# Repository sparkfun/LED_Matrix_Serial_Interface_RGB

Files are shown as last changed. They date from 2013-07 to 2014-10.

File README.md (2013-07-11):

LED Matrix Serial Interface-RGB
===============================

[LED Matrix-Serial Interface RGB  
*LED Matrix - Serial Interface RGB (COM-00760)*](https://www.sparkfun.com/products/760)

This is a large sized RGB LED matrix with a backpack that has been designed to take SPI serial input and display any graphics you pass it.

Repository Contents
-------------------
* **/Firmware** - Any firmware that the part ships with, 
* **/Hardware** - All Eagle design files (.brd, .sch, .STL)

License Information
-------------------
The hardware is released under [Creative Commons Share-alike 3.0](http://creativecommons.org/licenses/by-sa/3.0/).  
All other code is open source so please feel free to do anything you want with it; you buy me a beer if you use this and we meet someday ([Beerware license](http://en.wikipedia.org/wiki/Beerware)).

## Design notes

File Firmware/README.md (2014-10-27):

LED Matrix Serial Interface RGB Firmware
=======================================

* Arduino_Examples - Example Arduino sketch for interfacing with the LED Matrix
* RGB_Backpack_v5 - Firmware that ships installed on the LED Matrix Backpack

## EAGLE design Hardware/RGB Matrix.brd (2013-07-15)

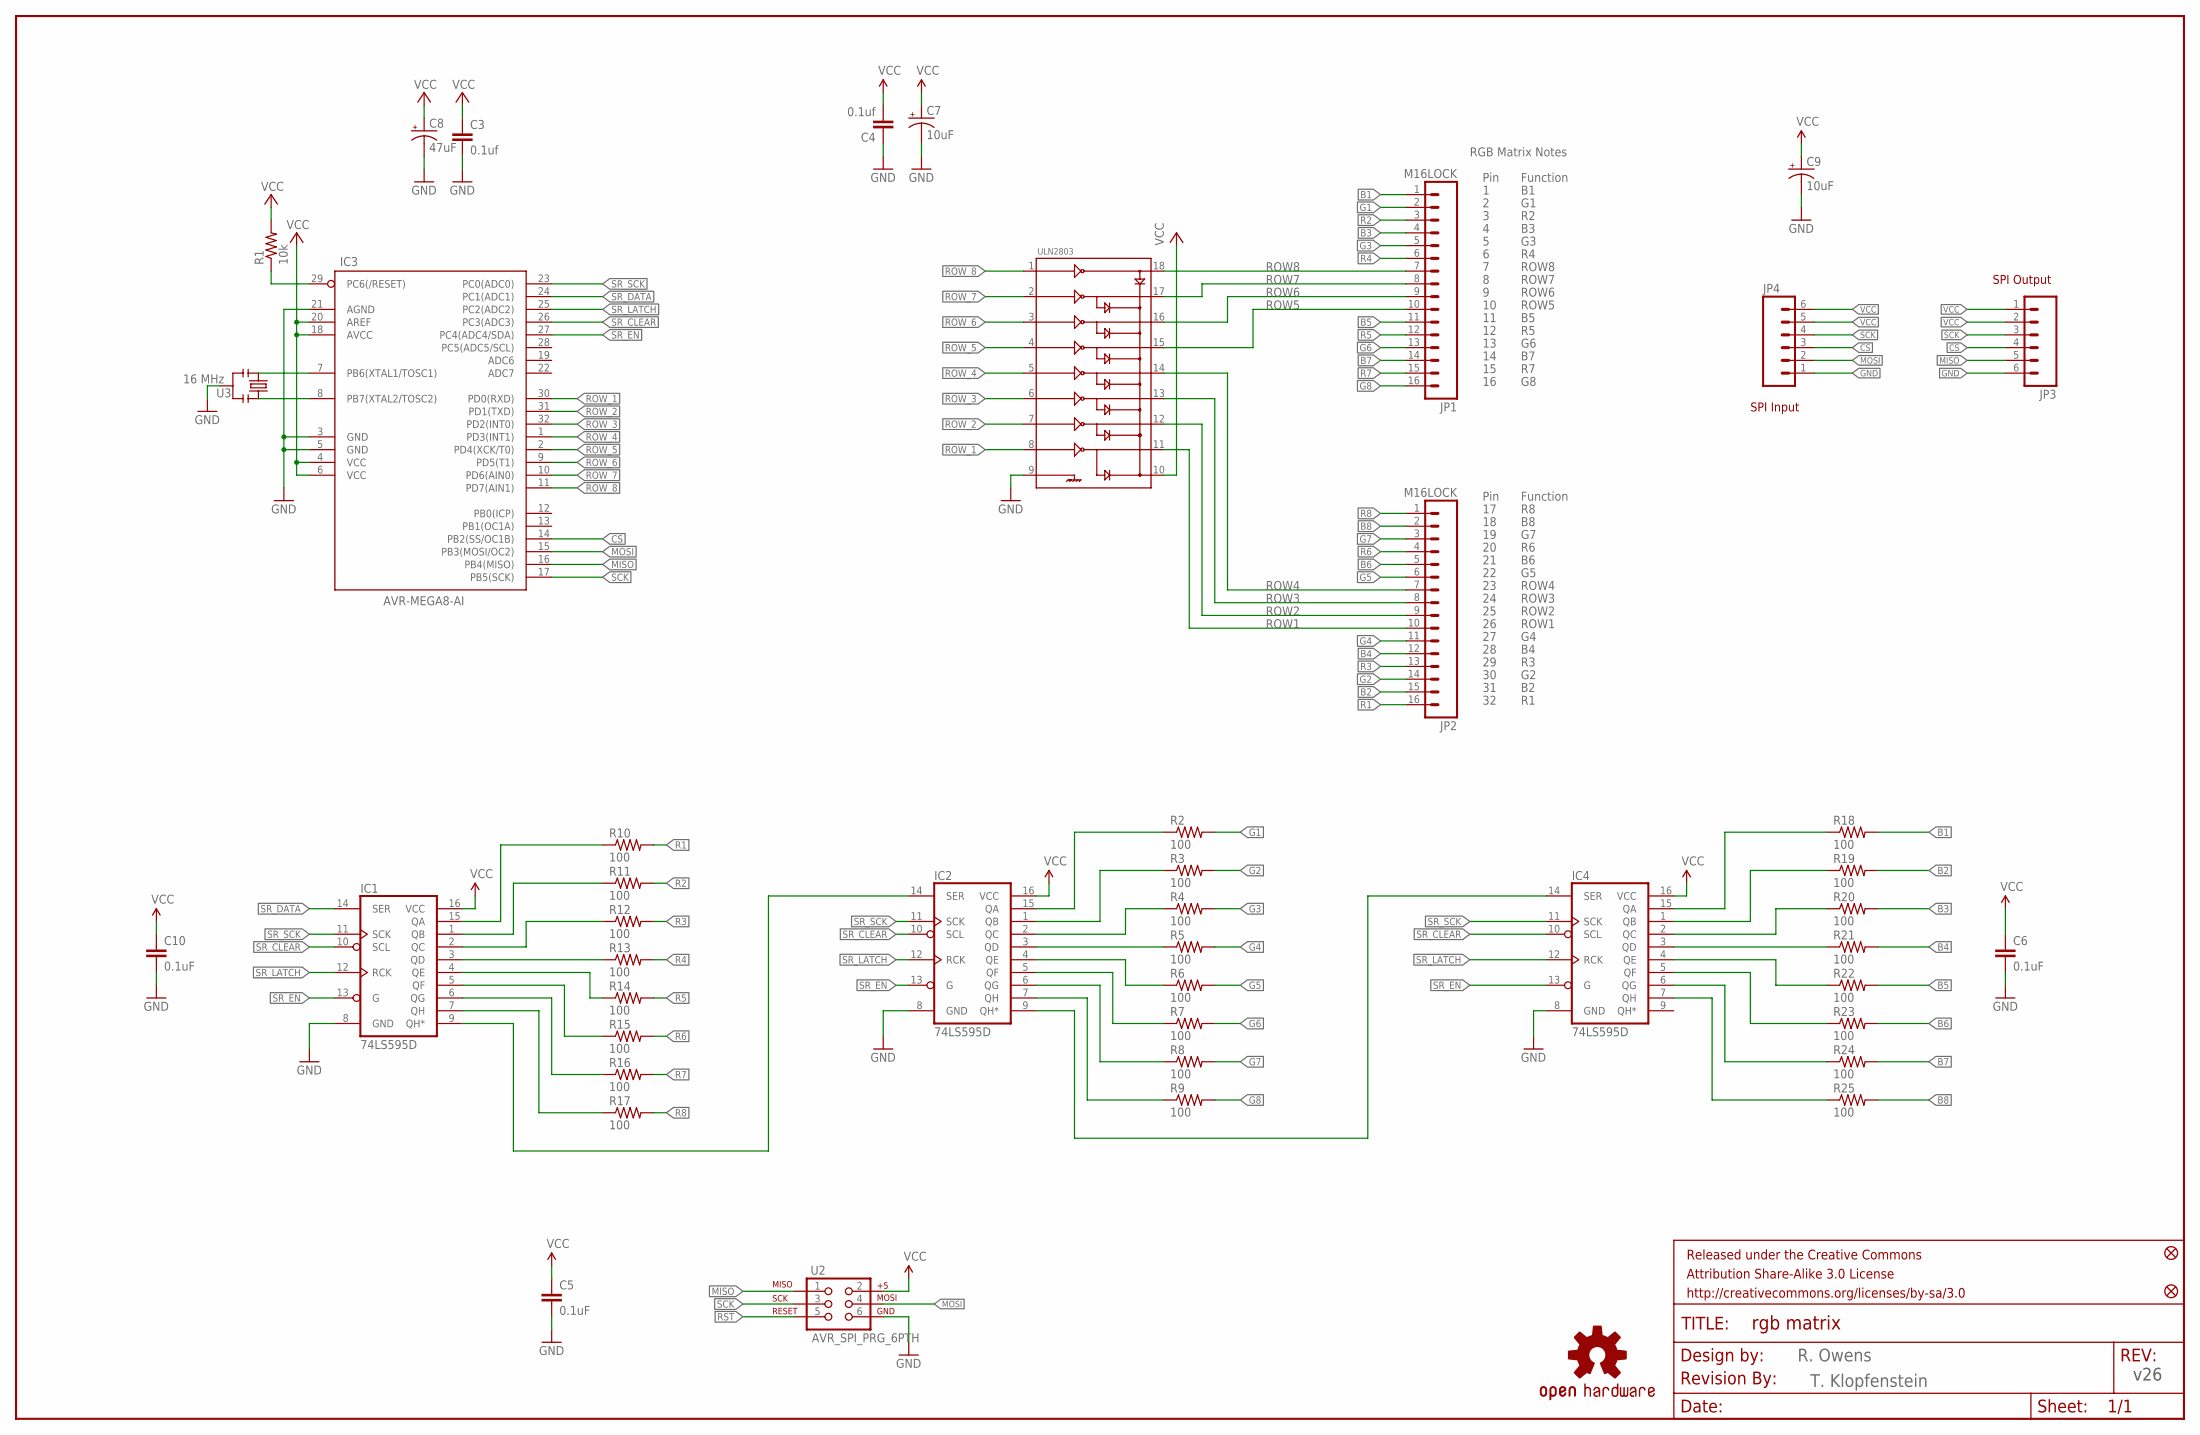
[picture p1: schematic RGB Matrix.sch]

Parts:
C3, C4: 0.1uf; 0603-CAP
C5, C6, C10: 0.1uF; 0603-CAP
C7, C9: 10uF; EIA3216
C8: 47uF; EIA3528
FRAME1: FRAME-LEDGER; CREATIVE_COMMONS
IC1, IC2, IC4: 74LS595D; SO16
IC3: AVR-MEGA8-AI; TQFP32-08
JP1, JP2: M16LOCK; 1X16_LOCK
JP3: M06SMD; 1X06-SMD
JP4: M06LOCK; 1X06_LOCK
LOGO1: OSHW-LOGOL; OSHW-LOGO-L
R1: 10k; 0603-RES
R2, R3, R4, R5, R6, R7, R8, R9, R10, R11, R12, R13, R14, R15, R16, R17, R18, R19, R20, R21, R22, R23, R24, R25: 100; 0603-RES
U2: AVR_SPI_PRG_6PTH; 2X3
U3: 16 MHz; RESONATOR-SMD
U$1, U$3: FIDUCIAL1X2; FIDUCIAL-1X2
U$2: REVISION
ULN2803: ULN2803SOICW; SO18L

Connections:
B1: JP1.1, R18.2
B2: JP2.15, R19.2
B3: JP1.4, R20.2
B4: JP2.12, R21.2
B5: JP1.11, R22.2
B6: JP2.5, R23.2
B7: JP1.14, R24.2
B8: JP2.2, R25.2
CS: IC3.14 (PB2(SS/OC1B)), JP3.4, JP4.3
G1: JP1.2, R2.2
G2: JP2.14, R3.2
G3: JP1.5, R4.2
G4: JP2.11, R5.2
G5: JP2.6, R6.2
G6: JP1.13, R7.2
G7: JP2.3, R8.2
G8: JP1.16, R9.2
GND: C3.2, C4.1, C5.2, C6.2, C7.C (-), C8.C (-), C9.C (-), C10.2, IC1.8 (GND), IC2.8 (GND), IC3.3 (GND), IC3.5 (GND), IC3.21 (AGND), IC4.8 (GND), JP3.6, JP4.1, U2.6, U3.2, ULN2803.9
MISO: IC3.16 (PB4(MISO)), JP3.5, U2.1
MOSI: IC3.15 (PB3(MOSI/OC2)), JP4.2, U2.4
unnamed: IC3.7 (PB6(XTAL1/TOSC1)), U3.1
unnamed: IC3.8 (PB7(XTAL2/TOSC2)), U3.3
unnamed: IC1.9 (QH*), IC2.14 (SER)
unnamed: IC1.15 (QA), R10.1
unnamed: IC1.1 (QB), R11.1
unnamed: IC1.2 (QC), R12.1
unnamed: IC1.3 (QD), R13.1
unnamed: IC2.9 (QH*), IC4.14 (SER)
unnamed: IC1.4 (QE), R14.1
unnamed: IC1.5 (QF), R15.1
unnamed: IC1.6 (QG), R16.1
unnamed: IC1.7 (QH), R17.1
unnamed: IC2.15 (QA), R2.1
unnamed: IC2.1 (QB), R3.1
unnamed: IC2.2 (QC), R4.1
unnamed: IC2.3 (QD), R5.1
unnamed: IC2.4 (QE), R6.1
unnamed: IC2.5 (QF), R7.1
unnamed: IC2.6 (QG), R8.1
unnamed: IC2.7 (QH), R9.1
unnamed: IC4.15 (QA), R18.1
unnamed: IC4.1 (QB), R19.1
unnamed: IC4.2 (QC), R20.1
unnamed: IC4.3 (QD), R21.1
unnamed: IC4.4 (QE), R22.1
unnamed: IC4.5 (QF), R23.1
unnamed: IC4.6 (QG), R24.1
unnamed: IC4.7 (QH), R25.1
R1: JP2.16, R10.2
R2: JP1.3, R11.2
R3: JP2.13, R12.2
R4: JP1.6, R13.2
R5: JP1.12, R14.2
R6: JP2.4, R15.2
R7: JP1.15, R16.2
R8: JP2.1, R17.2
ROW1: JP2.10, ULN2803.11
ROW2: JP2.9, ULN2803.12
ROW3: JP2.8, ULN2803.13
ROW4: JP2.7, ULN2803.14
ROW5: JP1.10, ULN2803.15
ROW6: JP1.9, ULN2803.16
ROW7: JP1.8, ULN2803.17
ROW8: JP1.7, ULN2803.18
ROW_1: IC3.30 (PD0(RXD)), ULN2803.8
ROW_2: IC3.31 (PD1(TXD)), ULN2803.7
ROW_3: IC3.32 (PD2(INT0)), ULN2803.6
ROW_4: IC3.1 (PD3(INT1)), ULN2803.5
ROW_5: IC3.2 (PD4(XCK/T0)), ULN2803.4
ROW_6: IC3.9 (PD5(T1)), ULN2803.3
ROW_7: IC3.10 (PD6(AIN0)), ULN2803.2
ROW_8: IC3.11 (PD7(AIN1)), ULN2803.1
RST: IC3.29 (PC6(/RESET)), R1.1, U2.5
SCK: IC3.17 (PB5(SCK)), JP3.3, JP4.4, U2.3
SR_CLEAR: IC1.10 (SCL), IC2.10 (SCL), IC3.26 (PC3(ADC3)), IC4.10 (SCL)
SR_DATA: IC1.14 (SER), IC3.24 (PC1(ADC1))
SR_EN: IC1.13 (G), IC2.13 (G), IC3.27 (PC4(ADC4/SDA)), IC4.13 (G)
SR_LATCH: IC1.12 (RCK), IC2.12 (RCK), IC3.25 (PC2(ADC2)), IC4.12 (RCK)
SR_SCK: IC1.11 (SCK), IC2.11 (SCK), IC3.23 (PC0(ADC0)), IC4.11 (SCK)
VCC: C3.1, C4.2, C5.1, C6.1, C7.A (+), C8.A (+), C9.A (+), C10.1, IC1.16 (VCC), IC2.16 (VCC), IC3.4 (VCC), IC3.6 (VCC), IC3.18 (AVCC), IC3.20 (AREF), IC4.16 (VCC), JP3.1, JP3.2, JP4.5, JP4.6, R1.2, U2.2, ULN2803.10

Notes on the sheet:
Pin
Function
ROW8
ROW7
ROW6
ROW5
ROW4
ROW3
RGB Matrix Notes
ROW2
ROW1
SPI Output
SPI Input
R. Owens
v26
T. Klopfenstein

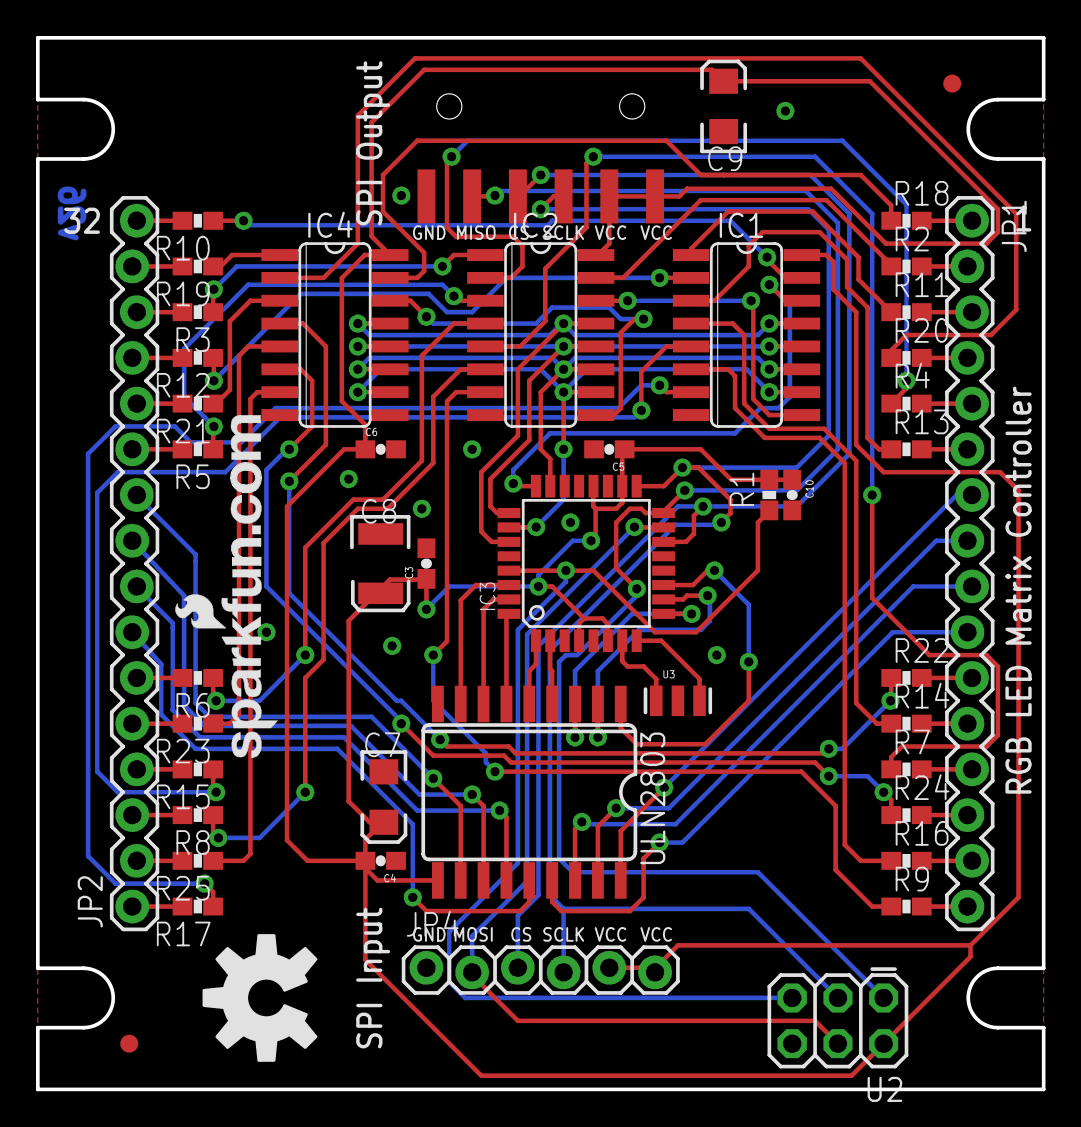
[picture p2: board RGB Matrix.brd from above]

Board: 2 copper layers, 55.9 x 58.4 mm, 50 parts (0 on the bottom side), 80 nets.

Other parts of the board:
U$8: SFE-NEW-WEBLOGO

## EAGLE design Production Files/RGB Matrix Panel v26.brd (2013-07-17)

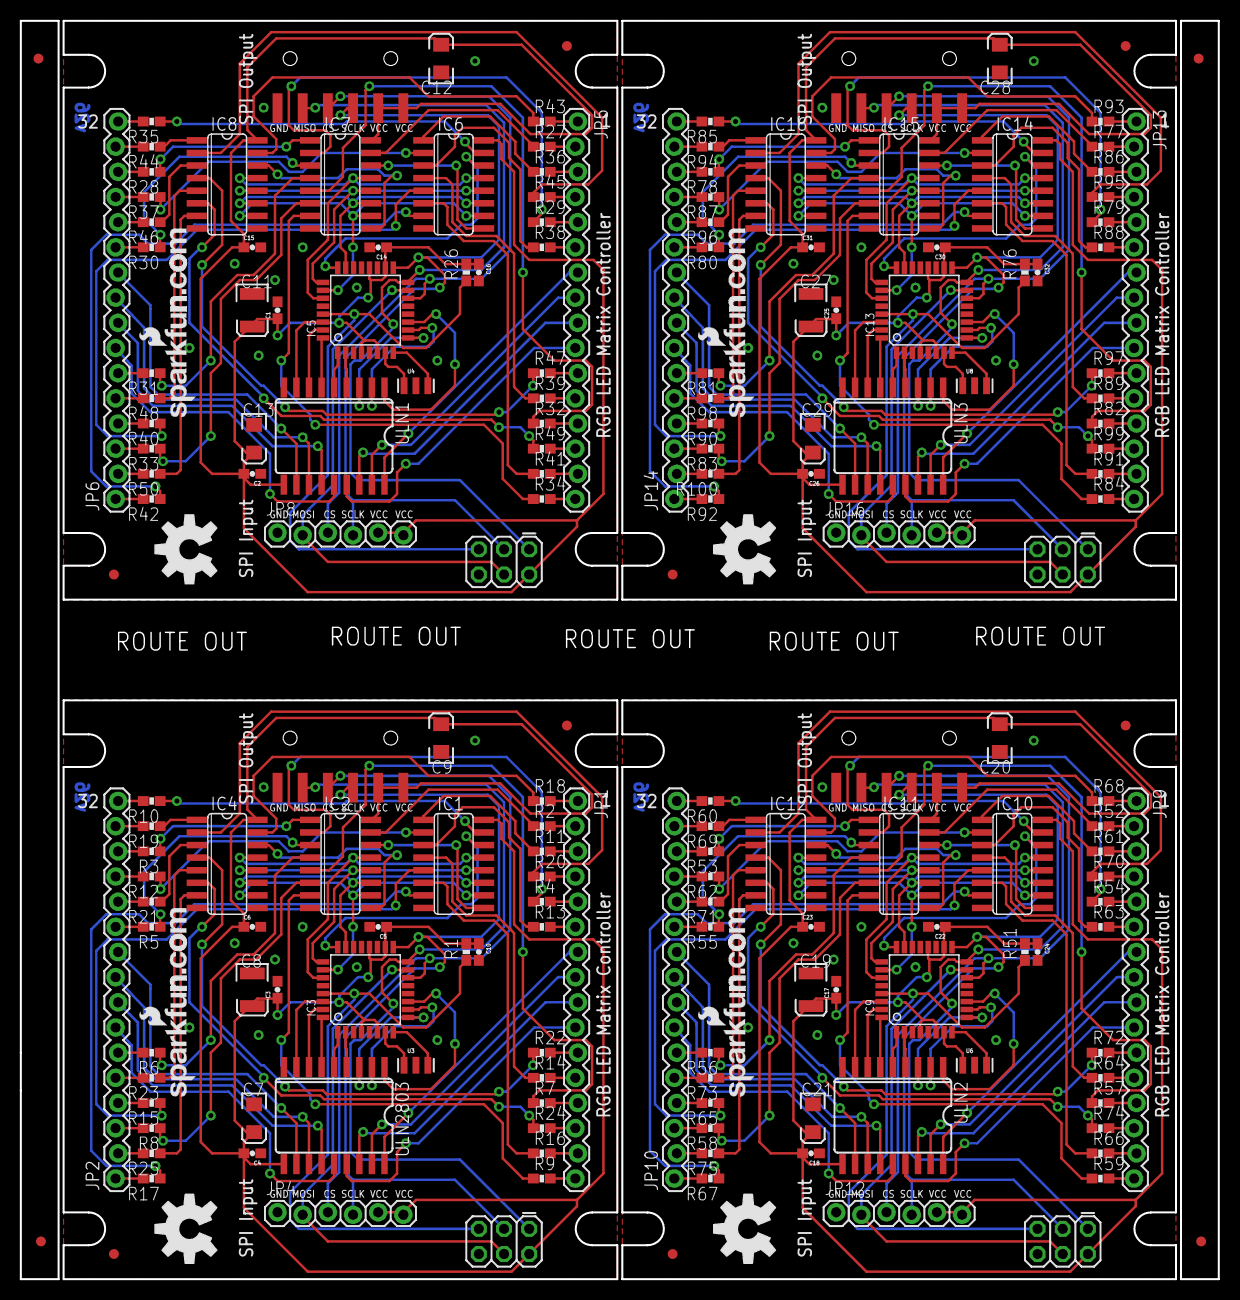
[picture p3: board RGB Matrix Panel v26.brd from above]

Board: 2 copper layers, 120.9 x 127.0 mm, 196 parts (0 on the bottom side), 320 nets.

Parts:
C1, C2, C3, C4, C17, C18, C25, C26: 0.1uf; 0603-CAP
C5, C6, C10, C14, C15, C16, C22, C23, C24, C30, C31, C32: 0.1uF; 0603-CAP
C7, C9, C12, C13, C20, C21, C28, C29: 10uF; EIA3216
C8, C11, C19, C27: 47uF; EIA3528
E$1, E$2, E$3, E$4: FIDUCIAL-1X2
IC1, IC2, IC4, IC6, IC7, IC8, IC10, IC11, IC12, IC14, IC15, IC16: 74LS595D; SO16
IC3, IC5, IC9, IC13: AVR-MEGA8-AI; TQFP32-08
JP1, JP2, JP5, JP6, JP9, JP10, JP13, JP14: M16LOCK; 1X16_LOCK
JP3, JP7, JP11, JP15: 1X06-SMD
JP4, JP8, JP12, JP16: 1X06_LOCK
LOGO1, LOGO2, LOGO3, LOGO4: OSHW-LOGOL; OSHW-LOGO-L
R1, R26, R51, R76: 10k; 0603-RES
R2, R3, R4, R5, R6, R7, R8, R9, R10, R11, R12, R13, R14, R15, R16, R17, R18, R19, R20, R21, R22, R23, R24, R25, R27, R28, R29, R30, R31, R32, R33, R34, R35, R36, R37, R38, R39, R40, R41, R42, R43, R44, R45, R46, R47, R48, R49, R50, R52, R53, R54, R55, R56, R57, R58, R59, R60, R61, R62, R63, R64, R65, R66, R67, R68, R69, R70, R71, R72, R73, R74, R75, R77, R78, R79, R80, R81, R82, R83, R84, R85, R86, R87, R88, R89, R90, R91, R92, R93, R94, R95, R96, R97, R98, R99, R100: 100; 0603-RES
U1, U2, U5, U7: AVR_SPI_PRG_6PTH; 2X3
U3, U4, U6, U8: 16 MHz; RESONATOR-SMD
U$1, U$2, U$3, U$4, U$6, U$7, U$10, U$11: FIDUCIAL1X2; FIDUCIAL-1X2
U$5, U$8, U$9, U$12: SFE-NEW-WEBLOGO
ULN1, ULN2, ULN3, ULN2803: SO18L

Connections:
B1: JP1.1, R18.2
B2: JP2.15, R19.2
B3: JP1.4, R20.2
B4: JP2.12, R21.2
B5: JP1.11, R22.2
B6: JP2.5, R23.2
B7: JP1.14, R24.2
B8: JP2.2, R25.2
B9: JP5.1, R43.2
B10: JP6.15, R44.2
B11: JP5.4, R45.2
B12: JP6.12, R46.2
B13: JP5.11, R47.2
B14: JP6.5, R48.2
B15: JP5.14, R49.2
B16: JP6.2, R50.2
B17: JP9.1, R68.2
B18: JP10.15, R69.2
B19: JP9.4, R70.2
B20: JP10.12, R71.2
B21: JP9.11, R72.2
B22: JP10.5, R73.2
B23: JP9.14, R74.2
B24: JP10.2, R75.2
B25: JP13.1, R93.2
B26: JP14.15, R94.2
B27: JP13.4, R95.2
B28: JP14.12, R96.2
B29: JP13.11, R97.2
B30: JP14.5, R98.2
B31: JP13.14, R99.2
B32: JP14.2, R100.2
CS: IC3.14, JP3.4, JP4.3
CS1: IC5.14, JP7.4, JP8.3
CS2: IC9.14, JP11.4, JP12.3
CS3: IC13.14, JP15.4, JP16.3
G1: JP1.2, R2.2
G2: JP2.14, R3.2
G3: JP1.5, R4.2
G4: JP2.11, R5.2
G5: JP2.6, R6.2
G6: JP1.13, R7.2
G7: JP2.3, R8.2
G8: JP1.16, R9.2
G9: JP5.2, R27.2
G10: JP6.14, R28.2
G11: JP5.5, R29.2
G12: JP6.11, R30.2
G13: JP6.6, R31.2
G14: JP5.13, R32.2
G15: JP6.3, R33.2
G16: JP5.16, R34.2
G17: JP9.2, R52.2
G18: JP10.14, R53.2
G19: JP9.5, R54.2
G20: JP10.11, R55.2
G21: JP10.6, R56.2
G22: JP9.13, R57.2
G23: JP10.3, R58.2
G24: JP9.16, R59.2
G25: JP13.2, R77.2
G26: JP14.14, R78.2
G27: JP13.5, R79.2
G28: JP14.11, R80.2
G29: JP14.6, R81.2
G30: JP13.13, R82.2
G31: JP14.3, R83.2
G32: JP13.16, R84.2
GND: C3.2, C4.1, C5.2, C6.2, C7.C, C8.C, C9.C, C10.2, IC1.8, IC2.8, IC3.3, IC3.5, IC3.21, IC4.8, JP3.6, JP4.1, U2.6, U3.2, ULN2803.9
GND1: C1.2, C2.1, C11.C, C12.C, C13.C, C14.2, C15.2, C16.2, IC5.3, IC5.5, IC5.21, IC6.8, IC7.8, IC8.8, JP7.6, JP8.1, U1.6, U4.2, ULN1.9
GND2: C17.2, C18.1, C19.C, C20.C, C21.C, C22.2, C23.2, C24.2, IC9.3, IC9.5, IC9.21, IC10.8, IC11.8, IC12.8, JP11.6, JP12.1, U5.6, U6.2, ULN2.9
GND3: C25.2, C26.1, C27.C, C28.C, C29.C, C30.2, C31.2, C32.2, IC13.3, IC13.5, IC13.21, IC14.8, IC15.8, IC16.8, JP15.6, JP16.1, U7.6, U8.2, ULN3.9
MISO: IC3.16, JP3.5, U2.1
MISO1: IC5.16, JP7.5, U1.1
MISO2: IC9.16, JP11.5, U5.1
MISO3: IC13.16, JP15.5, U7.1
MOSI: IC3.15, JP4.2, U2.4
MOSI1: IC5.15, JP8.2, U1.4
MOSI2: IC9.15, JP12.2, U5.4
MOSI3: IC13.15, JP16.2, U7.4
unnamed: IC3.7, U3.1
unnamed: IC3.8, U3.3
unnamed: IC6.15, R35.1
unnamed: IC6.1, R36.1
unnamed: IC6.2, R37.1
unnamed: IC6.3, R38.1
unnamed: IC6.4, R39.1
unnamed: IC6.5, R40.1
unnamed: IC6.6, R41.1
unnamed: IC6.7, R42.1
unnamed: IC1.9, IC2.14
unnamed: IC1.15, R10.1
unnamed: IC1.1, R11.1
unnamed: IC1.2, R12.1
unnamed: IC1.3, R13.1
unnamed: IC2.9, IC4.14
unnamed: IC7.15, R27.1
unnamed: IC1.4, R14.1
unnamed: IC1.5, R15.1
unnamed: IC1.6, R16.1
unnamed: IC1.7, R17.1
unnamed: IC2.15, R2.1
unnamed: IC2.1, R3.1
unnamed: IC2.2, R4.1
unnamed: IC2.3, R5.1
unnamed: IC2.4, R6.1
unnamed: IC2.5, R7.1
unnamed: IC2.6, R8.1
unnamed: IC2.7, R9.1
unnamed: IC7.1, R28.1
unnamed: IC7.2, R29.1
unnamed: IC4.15, R18.1
unnamed: IC4.1, R19.1
unnamed: IC4.2, R20.1
unnamed: IC4.3, R21.1
unnamed: IC4.4, R22.1
unnamed: IC4.5, R23.1
unnamed: IC4.6, R24.1
unnamed: IC4.7, R25.1
unnamed: IC7.3, R30.1
unnamed: IC7.4, R31.1
unnamed: IC7.5, R32.1
unnamed: IC7.6, R33.1
unnamed: IC7.7, R34.1
unnamed: IC8.15, R43.1
unnamed: IC8.1, R44.1
unnamed: IC8.2, R45.1
unnamed: IC8.3, R46.1
unnamed: IC8.4, R47.1
unnamed: IC8.5, R48.1
unnamed: IC8.6, R49.1
unnamed: IC8.7, R50.1
unnamed: IC6.9, IC7.14
unnamed: IC7.9, IC8.14
unnamed: IC5.7, U4.1
unnamed: IC5.8, U4.3
unnamed: IC10.15, R60.1
unnamed: IC10.1, R61.1
unnamed: IC10.2, R62.1
unnamed: IC10.3, R63.1
unnamed: IC10.4, R64.1
unnamed: IC10.5, R65.1
unnamed: IC10.6, R66.1
unnamed: IC10.7, R67.1
unnamed: IC11.15, R52.1
unnamed: IC11.1, R53.1
unnamed: IC11.2, R54.1
unnamed: IC11.3, R55.1
unnamed: IC11.4, R56.1
unnamed: IC11.5, R57.1
unnamed: IC11.6, R58.1
unnamed: IC11.7, R59.1
unnamed: IC12.15, R68.1
unnamed: IC12.1, R69.1
unnamed: IC12.2, R70.1
unnamed: IC12.3, R71.1
unnamed: IC12.4, R72.1
unnamed: IC12.5, R73.1
unnamed: IC12.6, R74.1
unnamed: IC12.7, R75.1
unnamed: IC10.9, IC11.14
unnamed: IC11.9, IC12.14
unnamed: IC9.7, U6.1
unnamed: IC9.8, U6.3
unnamed: IC14.15, R85.1
unnamed: IC14.1, R86.1
unnamed: IC14.2, R87.1
unnamed: IC14.3, R88.1
unnamed: IC14.4, R89.1
unnamed: IC14.5, R90.1
unnamed: IC14.6, R91.1
unnamed: IC14.7, R92.1
unnamed: IC15.15, R77.1
unnamed: IC15.1, R78.1
unnamed: IC15.2, R79.1
unnamed: IC15.3, R80.1
unnamed: IC15.4, R81.1
unnamed: IC15.5, R82.1
unnamed: IC15.6, R83.1
unnamed: IC15.7, R84.1
unnamed: IC16.15, R93.1
unnamed: IC16.1, R94.1
unnamed: IC16.2, R95.1
unnamed: IC16.3, R96.1
unnamed: IC16.4, R97.1
unnamed: IC16.5, R98.1
unnamed: IC16.6, R99.1
unnamed: IC16.7, R100.1
unnamed: IC14.9, IC15.14
unnamed: IC15.9, IC16.14
unnamed: IC13.7, U8.1
unnamed: IC13.8, U8.3
R1: JP2.16, R10.2
R2: JP1.3, R11.2
R3: JP2.13, R12.2
R4: JP1.6, R13.2
R5: JP1.12, R14.2
R6: JP2.4, R15.2
R7: JP1.15, R16.2
R8: JP2.1, R17.2
R9: JP6.16, R35.2
R10: JP5.3, R36.2
R11: JP6.13, R37.2
R12: JP5.6, R38.2
R13: JP5.12, R39.2
R14: JP6.4, R40.2
R15: JP5.15, R41.2
R16: JP6.1, R42.2
R17: JP10.16, R60.2
R18: JP9.3, R61.2
R19: JP10.13, R62.2
R20: JP9.6, R63.2
R21: JP9.12, R64.2
R22: JP10.4, R65.2
R23: JP9.15, R66.2
R24: JP10.1, R67.2
R25: JP14.16, R85.2
R26: JP13.3, R86.2
R27: JP14.13, R87.2
R28: JP13.6, R88.2
R29: JP13.12, R89.2
R30: JP14.4, R90.2
R31: JP13.15, R91.2
R32: JP14.1, R92.2
ROW1: JP2.10, ULN2803.11
ROW2: JP2.9, ULN2803.12
ROW3: JP2.8, ULN2803.13
ROW4: JP2.7, ULN2803.14
ROW5: JP1.10, ULN2803.15
ROW6: JP1.9, ULN2803.16
ROW7: JP1.8, ULN2803.17
ROW8: JP1.7, ULN2803.18
ROW9: JP5.7, ULN1.18
ROW10: JP5.8, ULN1.17
ROW11: JP5.9, ULN1.16
ROW12: JP5.10, ULN1.15
ROW13: JP6.7, ULN1.14
ROW14: JP6.8, ULN1.13
ROW15: JP6.9, ULN1.12
ROW16: JP6.10, ULN1.11
ROW17: JP9.7, ULN2.18
ROW18: JP9.8, ULN2.17
ROW19: JP9.9, ULN2.16
ROW20: JP9.10, ULN2.15
ROW21: JP10.7, ULN2.14
ROW22: JP10.8, ULN2.13
ROW23: JP10.9, ULN2.12
ROW24: JP10.10, ULN2.11
ROW25: JP13.7, ULN3.18
ROW26: JP13.8, ULN3.17
ROW27: JP13.9, ULN3.16
ROW28: JP13.10, ULN3.15
ROW29: JP14.7, ULN3.14
ROW30: JP14.8, ULN3.13
ROW31: JP14.9, ULN3.12
ROW32: JP14.10, ULN3.11
ROW_1: IC3.30, ULN2803.8
ROW_2: IC3.31, ULN2803.7
ROW_3: IC3.32, ULN2803.6
ROW_4: IC3.1, ULN2803.5
ROW_5: IC3.2, ULN2803.4
ROW_6: IC3.9, ULN2803.3
ROW_7: IC3.10, ULN2803.2
ROW_8: IC3.11, ULN2803.1
ROW_9: IC5.11, ULN1.1
ROW_10: IC5.10, ULN1.2
ROW_11: IC5.9, ULN1.3
ROW_12: IC5.2, ULN1.4
ROW_13: IC5.1, ULN1.5
ROW_14: IC5.32, ULN1.6
ROW_15: IC5.31, ULN1.7
ROW_16: IC5.30, ULN1.8
ROW_17: IC9.11, ULN2.1
ROW_18: IC9.10, ULN2.2
ROW_19: IC9.9, ULN2.3
ROW_20: IC9.2, ULN2.4
ROW_21: IC9.1, ULN2.5
ROW_22: IC9.32, ULN2.6
ROW_23: IC9.31, ULN2.7
ROW_24: IC9.30, ULN2.8
ROW_25: IC13.11, ULN3.1
ROW_26: IC13.10, ULN3.2
ROW_27: IC13.9, ULN3.3
ROW_28: IC13.2, ULN3.4
ROW_29: IC13.1, ULN3.5
ROW_30: IC13.32, ULN3.6
ROW_31: IC13.31, ULN3.7
ROW_32: IC13.30, ULN3.8
RST: IC3.29, R1.1, U2.5
RST1: IC5.29, R26.1, U1.5
RST2: IC9.29, R51.1, U5.5
RST3: IC13.29, R76.1, U7.5
SCK: IC3.17, JP3.3, JP4.4, U2.3
SCK1: IC5.17, JP7.3, JP8.4, U1.3
SCK2: IC9.17, JP11.3, JP12.4, U5.3
SCK3: IC13.17, JP15.3, JP16.4, U7.3
SR_CLEAR: IC1.10, IC2.10, IC3.26, IC4.10
SR_CLEAR1: IC5.26, IC6.10, IC7.10, IC8.10
SR_CLEAR2: IC9.26, IC10.10, IC11.10, IC12.10
SR_CLEAR3: IC13.26, IC14.10, IC15.10, IC16.10
SR_DATA: IC1.14, IC3.24
SR_DATA1: IC5.24, IC6.14
SR_DATA2: IC9.24, IC10.14
SR_DATA3: IC13.24, IC14.14
SR_EN: IC1.13, IC2.13, IC3.27, IC4.13
SR_EN1: IC5.27, IC6.13, IC7.13, IC8.13
SR_EN2: IC9.27, IC10.13, IC11.13, IC12.13
SR_EN3: IC13.27, IC14.13, IC15.13, IC16.13
SR_LATCH: IC1.12, IC2.12, IC3.25, IC4.12
SR_LATCH1: IC5.25, IC6.12, IC7.12, IC8.12
SR_LATCH2: IC9.25, IC10.12, IC11.12, IC12.12
SR_LATCH3: IC13.25, IC14.12, IC15.12, IC16.12
SR_SCK: IC1.11, IC2.11, IC3.23, IC4.11
SR_SCK1: IC5.23, IC6.11, IC7.11, IC8.11
SR_SCK2: IC9.23, IC10.11, IC11.11, IC12.11
SR_SCK3: IC13.23, IC14.11, IC15.11, IC16.11
VCC: C3.1, C4.2, C5.1, C6.1, C7.A, C8.A, C9.A, C10.1, IC1.16, IC2.16, IC3.4, IC3.6, IC3.18, IC3.20, IC4.16, JP3.1, JP3.2, JP4.5, JP4.6, R1.2, U2.2, ULN2803.10
VCC1: C1.1, C2.2, C11.A, C12.A, C13.A, C14.1, C15.1, C16.1, IC5.4, IC5.6, IC5.18, IC5.20, IC6.16, IC7.16, IC8.16, JP7.1, JP7.2, JP8.5, JP8.6, R26.2, U1.2, ULN1.10
VCC2: C17.1, C18.2, C19.A, C20.A, C21.A, C22.1, C23.1, C24.1, IC9.4, IC9.6, IC9.18, IC9.20, IC10.16, IC11.16, IC12.16, JP11.1, JP11.2, JP12.5, JP12.6, R51.2, U5.2, ULN2.10
VCC3: C25.1, C26.2, C27.A, C28.A, C29.A, C30.1, C31.1, C32.1, IC13.4, IC13.6, IC13.18, IC13.20, IC14.16, IC15.16, IC16.16, JP15.1, JP15.2, JP16.5, JP16.6, R76.2, U7.2, ULN3.10

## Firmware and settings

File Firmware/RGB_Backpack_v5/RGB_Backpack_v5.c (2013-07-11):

/*
    9/13/10
    Copyright Spark Fun Electronics© 2010
    By Ryan Owens
    
    ATmega328p
    
    Uses RGB matrix backpack v2 (v24.brd)
	
	Program accepts values from SPI and displays them on the attached LED matrix. 
	Board can be configured for a multi-board configuration over SPI. 
	Board accepts NUM_BOARDS*NUM_LEDS bytes and then displays the LED values according
	to which position in the system the board is located.

*/

#include <inttypes.h>
#include <avr/io.h>
#include <avr/interrupt.h>
#include "RGB_Backpack_v5.h"

/*********************************************************
					  Global Variables
*********************************************************/
volatile uint8_t red_frame[64];		//Each byte in the buffer represents the brightness of the corresponding Red LED on the matrix
volatile uint8_t green_frame[64];	//Each byte in the buffer represents the brightness of the corresponding GREEN LED on the matrix
volatile uint8_t blue_frame[64];	//Each byte in the buffer represents the brightness of the corresponding BLUE LED on the matrix
volatile char myBuffer[512];		//Temporary Buffer that holds the incoming data from the SPI Bus. This data is parsed into the Red,Green and Blue Frame Buffers
volatile unsigned int frame_index = 0;	//Keeps track of the current index
volatile uint8_t new_frame;			//Flag telling the main firmware that enough data has been received and a new image can be displayed onto the matrix

volatile uint8_t timer_clicks=0;	//Used for PWM to generate different color brightnesses

volatile uint8_t NUM_BOARDS=0, RUN_COUNT=0;	
volatile char command_mode=0;
volatile char value=0;

const char numbers[] = {
0x00,0x00,0x84,0x82,0xFF,0x80,0x80,0x00, //49/ --> 1
0x00,0x00,0x82,0xC1,0xA1,0x91,0x8E,0x00, //50/ --> 2
0x00,0x00,0x42,0x81,0x89,0x76,0x00,0x00, //51/ --> 3
0x00,0x0F,0x08,0x08,0x08,0xFF,0x00,0x00, //52/ --> 4
0x00,0x00,0x00,0x8F,0x89,0x89,0x71,0x00, //53/ --> 5
0x00,0x00,0x7C,0x8A,0x89,0x89,0x71,0x00, //54/ --> 6
0x00,0x01,0xC1,0x31,0x09,0x05,0x03,0x00, //55/ --> 7
0x00,0x76,0x89,0x89,0x89,0x89,0x76,0x00, //56/ --> 8
};

/*********************************************************
			Interrupt Service Routines
*********************************************************/
/*
Usage:		Automatic as long as Global Interrupts are enabled (sei())
Purpose:	Initialize I/O, Setup SPI Hardware
Parameters:	None
Return:		None
*/
ISR (SIG_SPI) 
{
	cli();	//Halt Interrupts
	value=SPDR;	//Get the data from the SPI bus and put it into the temporary frame buffer
	//If we didn't receive a special character add the value to the display buffer
	if(!command_mode && value != '%' && value != 0x26)
	{
		myBuffer[frame_index++] = value;	//Add value to buffer and increment the index.
		SPDR = value;	//Send the value to the next board in the system.
	}
	//If the board is in command mode we need to set the NUM_BOARDS parameter
	if(command_mode){
		if(value > 0 && value < 9){	//Make sure we get a number between 0 and 8
			NUM_BOARDS=value;	//Set the NUM_BOARDS parameter for this matrix.	
			SPDR = (value-1);	//Send the NUM_BOARDS parameter to the next board in the system
			write_to_EEPROM(NUM_BOARDS_ADDRESS, NUM_BOARDS);	//Save the NUM_BOARDS to EEPROM
		}
		command_mode=0;	//Reset the command_mode flag
	}
	//If we get the '%' character we should enter command mode.
	if(value == '%'){
		command_mode=1;
		SPDR = '%';	//Send command mode to the next board too.
	}
	//0x26 is a special character to reset the frame index.
	if(value == 0x26){
		frame_index=0;
		SPDR = 0x26;
	}
	sei();	//Re-enable interrupts
}

/*********************************************************
						Main Code
*********************************************************/
int main (void)
{
	ioinit ();	//Initialize the I/O and the SPI port
	
	//Make sure all the pixels are working
	if(RUN_COUNT < 2)splash_screen();
	
	
	fillBoardCount(NUM_BOARDS);	//Put the board number into the display frame
	for(int i=0; i<5000; i++)
	{
		post_frames();
		timer_clicks = (timer_clicks + 1) & 0x07; //0b00000111; //Circular 0 to 7
	}
	
	sei();	//Enable Global Interrupts
	while(1)
	{
        if (PINB & (1<<CS)) //If CS goes high, SPI com is complete
		{
			new_frame=1;
		}
		//New frame is set when enought bytes have been received for the whole system
		if(new_frame==1){
			new_frame=0;	//Reset the frame flag.
			parse_frame(&myBuffer[(NUM_BOARDS-1)*64]);	//Parse the buffer at the location
				//for this specific board.
		}

		post_frames();	//Put the colors onto the matrix.
		//Increment clicks to determine LED brightness levels
		timer_clicks = (timer_clicks + 1) & 0x07; //0b00000111; //Circular 0 to 7
	}
	
	return (0);
}

/*********************************************************
						Functions
*********************************************************/
void ioinit (void)
{
	//1 = Output, 0 = Input
	DDRB = (1<<MISO);	//Set MISO as an output, all other SPI as inputs
	PORTB = (1<<MOSI)|(1<<CS)|(1<<SCK);	//Enable pull-ups on SPI Lines
	
	DDRC = 0x1F;	//Set outputs to the shift registers
	DDRD = 0xFF;	//All Port D pins are outputs to the Sync Driver

	//Set initial pin states
	sbi(PORTC, CLK);
	sbi(PORTC, CLR);
	sbi(PORTC, DATA);
	sbi(PORTC, LATCH);
	sbi(PORTC, EN); 
	
	//Setup the SPI Hardware
	SPCR = (1<<SPE) | (1<<SPIE)|(1<<SPR1)|(1<<SPR0); //Enable SPI, Enable SPI Interrupts
	
	//Load the NUM_BOARDS parameter from EEPROM
	RUN_COUNT = read_from_EEPROM(RUN_COUNT_ADDRESS);
	if(RUN_COUNT == 0xFF){
		RUN_COUNT = 1;
		write_to_EEPROM(RUN_COUNT_ADDRESS, RUN_COUNT);
		NUM_BOARDS=1;
		write_to_EEPROM(NUM_BOARDS_ADDRESS, NUM_BOARDS);
	}
	else{
		RUN_COUNT = read_from_EEPROM(RUN_COUNT_ADDRESS);
		if(RUN_COUNT < 10){
			RUN_COUNT+=1;
			write_to_EEPROM(RUN_COUNT_ADDRESS, RUN_COUNT);
		}
		NUM_BOARDS=read_from_EEPROM(NUM_BOARDS_ADDRESS);
		if(NUM_BOARDS > 8)NUM_BOARDS=1;
	}
		
}

void splash_screen(void)
{
	uint16_t i;
	cli();
	//Fill red
	for(i = 0 ; i < 64 ; i++)
	{
		red_frame[i] = 7;
		green_frame[i] = 0;
		blue_frame[i] = 0;
	}

	for(i = 0 ; i < 1000 ; i++)
		post_frames();

	//Fill green
	for(i = 0 ; i < 64 ; i++)
	{
		red_frame[i] = 0;
		green_frame[i] = 7;
		blue_frame[i] = 0;
	}

	for(i = 0 ; i < 1000 ; i++)
		post_frames();

	//Fill blue
	for(i = 0 ; i < 64 ; i++)
	{
		red_frame[i] = 0;
		green_frame[i] = 0;
		blue_frame[i] = 7;
	}

	for(i = 0 ; i < 1000 ; i++)
		 post_frames(); 		 

	PORTD = 0; //Turn off display
}

void parse_frame(char * postBuffer)
{
    uint8_t color_value;
    
    for(int LED = 0 ; LED < 64 ; LED++)
    {
        color_value = postBuffer[63-LED];
        red_frame[LED] = (color_value & 0xE0) >> 5;	//(temp & 0b11100000) >> 5; Highes 3 bits represent the Red value for the current LED
        green_frame[LED] = (color_value & 0x1C) >> 2; 	//(temp & 0b00011100) >> 2; Next 3 bits represent the Green value for the current LED
        blue_frame[LED] = (color_value & 0x03); 		//(temp & 0b00000011); Final 2 bits represent the Blue value for the current LED
    }
    new_frame = 0; //Reset new frame flag
}

void post_frames(void)
{	
	for(char row = 0 ; row < 8; row++)shift_out_line(row);	//Send all 8 rows of colors to the Matrix
}

void shift_out_line(volatile uint8_t row_num)
{
	cbi(PORTC, LATCH);	//Disable the shift registers

	//Send Red Values
	for(uint8_t LED = row_num*8 ; LED < (row_num*8)+8 ; LED++) //Step through bits
	{
		cbi(PORTC, CLK);	//Lower the shift register clock so we can configure the data
		
		//Compare the current color value to timer_clicks to Pulse Width Modulate the LED to create the designated brightness
		if(timer_clicks < red_frame[LED])
			sbi(PORTC, DATA);
		else
			cbi(PORTC, DATA);

		sbi(PORTC, CLK);	//Raise the shift register clock to lock in the data
	}
	//Send Blue Values
	for(uint8_t LED = row_num*8 ; LED < (row_num*8)+8 ; LED++) //Step through bits
	{
		cbi(PORTC, CLK);	//Lower the shift register clock so we can configure the data
	
		//Compare the current color value to timer_clicks to Pulse Width Modulate the LED to create the designated brightness
		if(timer_clicks < blue_frame[LED])
			sbi(PORTC, DATA);
		else
			cbi(PORTC, DATA);

		sbi(PORTC, CLK);	//Raise the shift register clock to lock in the data
	}
	//Send Green Values
	for(uint8_t i = row_num*8 ; i < (row_num*8)+8 ; i++) //Step through bits
	{
		cbi(PORTC, CLK);	//Lower the shift register clock so we can configure the data
	
		//Compare the current color value to timer_clicks to Pulse Width Modulate the LED to create the designated brightness
		if(timer_clicks < green_frame[i])
			sbi(PORTC, DATA);
		else
			cbi(PORTC, DATA);

		sbi(PORTC, CLK);	//Raise the shift register clock to lock in the data
	}

	sbi(PORTC, EN);		//Disable the Shift Register Outputs
	sbi(PORTC, LATCH);	//Put the new data onto the outputs of the shift register

	PORTD = (1<<row_num); //Sink current through row (Turns colors 'ON' for the given row. Keep in mind that we can only display to 1 row at a time.)

	cbi(PORTC, EN);		//Enable the Shift Register Outputs
}

void delay_us(uint8_t x)
{
	TIFR0 = (1<<TOV0); //Clear any interrupt flags on Timer2
	TCNT0 = 256 - x; //256 - 125 = 131 : Preload timer 2 for x clicks. Should be 1us per click
	while( (TIFR0 & (1<<TOV0)) == 0);

	//Double the delay because we are using 16MHz and 8 prescalar

	TIFR0 = (1<<TOV0); //Clear any interrupt flags on Timer2
	TCNT0 = 256 - x; //256 - 125 = 131 : Preload timer 2 for x clicks. Should be 1us per click
	while( (TIFR0 & (1<<TOV0)) == 0);
}

void delay_ms(uint16_t x)
{
	for ( ; x > 0 ; x--)
	{
		delay_us(250);
		delay_us(250);
		delay_us(250);
		delay_us(250);
	}
}

void write_to_EEPROM(unsigned int Address, unsigned char Data)
{
    //Interrupts are globally disabled!
	
	while(EECR & (1<<EEPE)); //Wait for last Write to complete
	//May need to wait for Flash to complete also!
	EEAR = Address;			//Assign the Address Register with "Address"
	EEDR=Data;				//Put "Data" in the Data Register
	EECR |= (1<<EEMPE); 	//Write to Master Write Enable
	EECR |= (1<<EEPE);  	//Start Write by setting EE Write Enable
	
}

unsigned char read_from_EEPROM(unsigned int Address)
{
	//Interrupts are globally disabled!
	
	while(EECR & (1<<EEPE));	//Wait for last Write to complete
	EEAR = Address;				//Assign the Address Register with "Address"
	EECR |= (1<<EERE); 			//Start Read by writing to EER
	return EEDR;				//EEPROM Data is returned
}

void fillBoardCount(char number)
{
	number-=1;
	for(int column=7; column>=0; column--)
    {
        for(int row=0; row<8; row++)
        {
            if(numbers[number*8+column] & (1<<row))myBuffer[row*8+(7-column)]=0xE0;
            else myBuffer[row*8+(7-column)]=0x00;
        }
    }
	parse_frame(myBuffer);

}

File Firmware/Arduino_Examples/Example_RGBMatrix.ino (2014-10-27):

//Example_RGBMatrix.ino
//By: Ryan Owens @ SparkFun Electronics
// 
//modified 27 Oct 2014
//by Bobby Chan @ SparkFun Electronics

// This is example code to output an array to 
// the RGB Serial Backpack Matrix and set the position of
// a daisy chained matrix.

//Define the "Normal" Colors
#define BLACK   0x00
#define RED     0xE0
#define GREEN   0x1C
#define BLUE    0x03
#define YELLOW  RED|GREEN
#define ORANGE  0xFC
#define MAGENTA RED|BLUE
#define TEAL    BLUE|GREEN
#define WHITE   (RED|GREEN|BLUE)-0xA0

//Define the SPI Pin Numbers
#define SLAVESELECT 10//ss
#define DATAOUT     11//MOSI
#define DATAIN      12//MISO 
#define SPICLOCK    13//sck

//Define final array to output to LED Matrices (maximum of 8 matrices daisy chained)
//Ex.) if you have 1 matrix, you have an array of 64=64*1
//     if you have 2 matrices, you have an array of 128=64*2
//     if you have 3 matrices, you have an array of 194=64*3
const int num_matrix = 1; //define number of daisy chained matrices
char color_buffer[64*num_matrix]; //final array

//array to clear 1 matrix
char blank[]={
  BLACK, BLACK, BLACK, BLACK, BLACK, BLACK, BLACK, BLACK,
  BLACK, BLACK, BLACK, BLACK, BLACK, BLACK, BLACK, BLACK,
  BLACK, BLACK, BLACK, BLACK, BLACK, BLACK, BLACK, BLACK,
  BLACK, BLACK, BLACK, BLACK, BLACK, BLACK, BLACK, BLACK,
  BLACK, BLACK, BLACK, BLACK, BLACK, BLACK, BLACK, BLACK,
  BLACK, BLACK, BLACK, BLACK, BLACK, BLACK, BLACK, BLACK,
  BLACK, BLACK, BLACK, BLACK, BLACK, BLACK, BLACK, BLACK,
  BLACK, BLACK, BLACK, BLACK, BLACK, BLACK, BLACK, BLACK
};

//set LED Matrix Value for daisy chained LED Matrices
//maximum of 8 daisy chained LED Matrices
void set_matrix(){
  digitalWrite(SLAVESELECT, LOW); //Activate the RGB Matrix
  spi_transfer(0x25); //command character % == 0x25
  spi_transfer(0x02); //set LED matrix to position in daisy chain, must be between 0x01-0x08
  digitalWrite(SLAVESELECT, HIGH); //Deactivate the RGB Matrix
}

int p = 0; //dot position
int xMAX = 8;//max number column in 1 subset
int yMAX = 8;//max number row in 1 subset

void clear_buffer(){
  //start clearing array moving down rows
  for(int y=0; y<yMAX; y++){
    //clear array from the highest subset in daisy chained array
    for(int i=num_matrix; i>0; i--){
      //clear array from right to left
      for(int x=0; x<xMAX; x++){
        //current position that is being cleared
        p = (yMAX*y) + (x + (i-1)*(xMAX*yMAX));
        //clear by saving what is in the blank sub-array to your final array
        color_buffer[p] = blank[x];
      }
    }
  }
  matrix_write();//write array of colors to matrix
  delay(10);//allow some time for the final matrix to be seen  
}

void color_test(){
  //Load colors into the first row color buffer array. 
  //This will be the array of colors sent to the first RGB matrix.
  color_buffer[0]=BLACK;
  color_buffer[1]=RED;
  color_buffer[2]=GREEN;
  color_buffer[3]=BLUE;
  color_buffer[4]=YELLOW;
  color_buffer[5]=MAGENTA;
  color_buffer[6]=TEAL;
  color_buffer[7]=WHITE;

  matrix_write();//write array of colors to matrix
  delay(100);  //allow some time for the final matrix to be seen  
}

void setup(){  
  //----------SPI BUS SETUP----------
  SPCR = (1<<SPE)|(1<<MSTR)|(1<<SPR1);	//Enable SPI HW, Master Mode, divide clock by 16

  //Set the pin modes for the RGB matrix
  pinMode(DATAOUT, OUTPUT);
  pinMode(DATAIN, INPUT);
  pinMode(SPICLOCK,OUTPUT);
  pinMode(SLAVESELECT,OUTPUT);

  //Make sure the RGB matrix is deactivated
  digitalWrite(SLAVESELECT,HIGH); 
  //----------END SPI BUS SETUP----------

  //use this to set a LED Matrix to position in daisy chain
  //set_matrix();

  //make sure buffer is cleared before writing to matrices
  clear_buffer();

  //test colors
  color_test();

  //for debugging
  //Serial.begin(9600);
  //Serial.println("Initializing Matrix");
}

void loop(){

}

//display array on the LED Matrix/daisy chained LED Matrices
void matrix_write(){
  digitalWrite(SLAVESELECT, LOW); //Activate the RGB Matrix
  spi_transfer(0x26); //command char to reset frame index
  digitalWrite(SLAVESELECT, HIGH); //Deactivate the RGB Matrix

  digitalWrite(SLAVESELECT, LOW); //Activate the RGB Matrix
  //Send the color buffer to the RGB Matrix
  delayMicroseconds(500);

  for(int LED=0; LED<(64*num_matrix); LED++){
    spi_transfer(color_buffer[LED]);//send what is in buffer to the matrices
  }
  delayMicroseconds(500);//allow some time for the serial data to be sent 
  digitalWrite(SLAVESELECT, HIGH); //Deactivate the RGB Matrix
}

//Use this command to send a single color value to the RGB matrix.
//NOTE: You must send x number of color values to the RGB matrix
//      before it displays an image!
char spi_transfer(volatile char data){
  SPDR = data;                    // Start the transmission
  while (!(SPSR & (1<<SPIF))){     
    // Wait for the end of the transmission  
  };
  return SPDR;                    // return the received byte
}

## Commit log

2013-07-11 Updated board files for 0603 packages, OSHW logo
    [RGB Matrix.brd, RGB Matrix.sch]
2013-07-11 Adding LED Matrix firmware and example code
2013-07-15 Updated revision to symbol
    [RGB Matrix.brd, RGB Matrix.sch]
2013-07-17 Production ready v26
    created panel of 4
    [RGB Matrix Panel v26.brd]
2014-10-24 Example Code Revision for Arduino
    -renaming sketch file (it's slightly confusing with the firmware that is on the serial backpack controller)
    -"ORANGE" actually is YELLOW when you mix red and green...
    -made the functions more modular so customers can call the functions from anywhere in the sketch file
    -added the set_matrix() function to set the position daisy chained matrix using the command char "0x25"
    -added some code to navigate through each daisy chained matrix to make sure that the array is cleared before writing to the matrices
    -added some lines to reset the frame index "0x26" using the command char before transferring so that Arduino can write to the LED matrix
    [Example_RGBMatrix.ino]
2014-10-24 Remove old code
    Deleting old code with a revised Arduino sketch file that is more
    stable. The new firmware required some command lines to reset the frame
    index.
2014-10-27 Update Example_RGBMatrix.ino
    -Change character array to integer array for blank[]. This will cause problems in the future...
    -Modified matrix_write() to make the transfer more general for daisy chained LED Matrices.
    [Example_RGBMatrix.ino]

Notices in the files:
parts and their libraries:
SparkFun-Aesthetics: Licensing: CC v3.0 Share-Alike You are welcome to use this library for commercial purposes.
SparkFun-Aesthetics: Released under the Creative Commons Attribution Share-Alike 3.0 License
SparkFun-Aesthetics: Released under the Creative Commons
